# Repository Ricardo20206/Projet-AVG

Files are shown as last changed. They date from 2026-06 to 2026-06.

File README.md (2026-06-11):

# Projet-AVG

Carte électronique de **monitoring** basée sur un microcontrôleur **ESP32**, réalisée dans le cadre du projet **Équipe 4 — GROUPE WEED** (2026).

## Description

Ce dépôt contient la conception complète de la carte de monitoring AVG : schémas, routage PCB, bibliothèques de composants et documentation associée. Le projet est développé sous **Altium Designer**.

### Fonctionnalités principales

- Microcontrôleur **ESP32**
- Acquisition via **capteurs**
- Pilotage d'**actionneurs**
- Gestion d'un **circuit de priorité**
- Alimentation et **régulateurs**
- Interface **USB / UART**
- **Connecteurs** pour l'intégration système

## Structure du dépôt

| Dossier | Contenu |
|---|---|
| `10_doc_ext/` | Documentation externe (datasheets, recherches, …) |
| `20_doc_int/` | Documentation interne (suivi, notes de version, …)  |
| `30_src/` | Sources du projet Altium (schémas, PCB, bibliothèques) |
| `40_tmp/` | Fichiers temporaires (non versionnés) |
| `50_out/` | Fichiers générés (exports, sorties de fabrication) |
| `60_valid/` | Fichiers de validation et tests |

## Fichiers principaux (`30_src/`)

| Fichier / dossier | Description |
|---|---|
| `ESP32_Projet.PrjPcb` | Projet Altium principal |
| `Feuille_2_ESP32.SchDoc` | Schéma ESP32 |
| `Capteurs.SchDoc` | Schéma capteurs |
| `Actionneur.SchDoc` | Schéma actionneurs |
| `Circuit de priorité.SchDoc` | Schéma circuit de priorité |
| `Regulateurs.SchDoc` | Schéma alimentation / régulateurs |
| `Connecteurs.SchDoc` | Schéma connecteurs |
| `USB_UART.SchDoc` | Schéma interface USB / UART |
| `PCB/PCB11.PcbDoc` | Carte imprimée |
| `Rapport de la carte de monitoring AVG..pdf` | Rapport de conception |

## Prérequis

- [Altium Designer](https://www.altium.com/altium-designer) (version compatible avec les fichiers du projet)
- Accès aux bibliothèques `SCHLibrary.SchLib` et `PCBLibrary.PcbLib` incluses dans le dépôt

## Ouverture du projet

1. Cloner le dépôt :
   ```bash
   git clone https://github.com/Ricardo20206/Projet-AVG.git
   ```
2. Ouvrir Altium Designer.
3. Charger le fichier `30_src/ESP32_Projet.PrjPcb`.

## Équipe

**Équipe 4 — GROUPE WEED**

## Licence

À définir.

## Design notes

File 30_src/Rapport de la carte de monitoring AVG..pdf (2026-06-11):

MASTERE 1 ROBOTIQUE

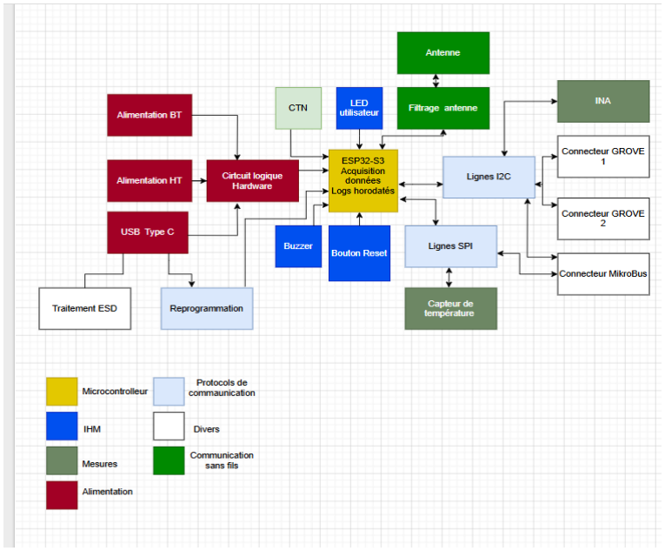
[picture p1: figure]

Rédiger par MBE SOB RICARDO

DOCUMENTATION TECHNIQUE – CARTE DE MONITORING4 AGV

Conception d'une carte embarquée pour AGV Ventec System Date: 07/05/2026
Groupe : WEED
Équipe :
MBE SOB Ricardo (CHEF DE PRPOJET) NGNINTEDEM TSOBENG Melkiade LE ROYER Edwin
MEYE ME NGUEMA Dan Irnel

ANALYSE FONCTIONNELLE (AF1 & AF2)

1- Architecture générale

Figure 1 : Architecture générale

2- Détail des blocs fonctionnels

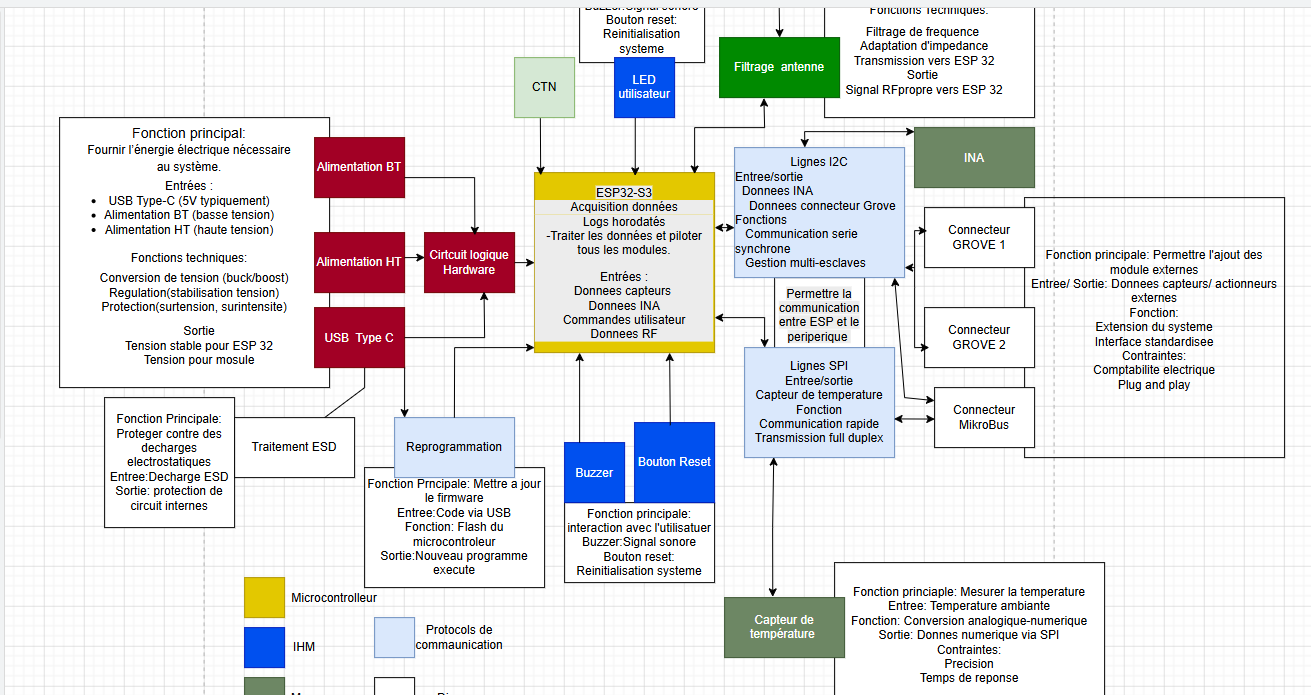
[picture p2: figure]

Figure 2 : Détail des blocs fonctionnels (AF2)

3- Alimentation

Les AGV de Ventec Systems sont équipés d'une batterie lithium 36V qui alimente en permanence l'ensemble des systèmes embarqués : motorisation, navigation, sécurité laser. Cette batterie ne peut pas être débranchée en cours d'exploitation, la couper reviendrait à couper l'alimentation des capteurs de sécurité et du système de navigation, ce qui est interdit par les procédures de sécurité en entrepôt. La carte de monitoring doit donc fonctionner en permanence sur cette source HT.
Lors d'une intervention de maintenance, le technicien doit avoir deux options pour se connecter à la carte sans couper le 36V :
- Brancher son PC portable via USB-C pour reprogrammer le firmware ou extraire les logs complets
- Connecter une batterie externe de service (3,7–10V) sur le connecteur BT pour alimenter la carte de façon isolée si le 36V doit être retiré pour une intervention lourde sur la batterie principale

La gestion de priorité (USB > BT > HT) garantit qu'une seule source est active à la fois et protège la carte dans tous les scénarios d'intervention. Pour éviter tout type d’accident, nous souhaitons un fonctionnement matériel, ce qui nous permet d’éviter les erreurs liées au firmware.

3.1- Conversion HT (36V) en 3V3
La conversion de cette tension est assurée par le régulateur de tension Buck LMR50410Y3FQDBVRQ1 qui convertit 36V_sh en 3.3V. Sur ce schéma l’entrée en tension vient de la sortie de la résistance shunt du capteur de courant et sa sortie en tension est nommée +3V3_HT.

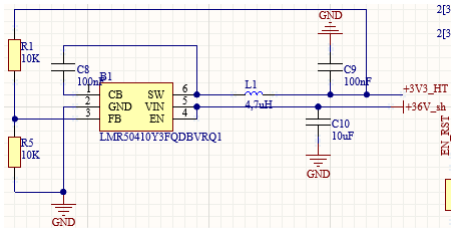
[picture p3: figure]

Figure 3 : Régulateur LMR50410Y3FQDBVRQ1

3.2- | conversion BT (3,7-10V) en 3V3
Cette | conversion est assurée par le | régulateur de tension | Buck
TPS62056DGSG4. Sur ce schéma l’entrée en tension est nommée +10V et la sortie +3V3_BT.

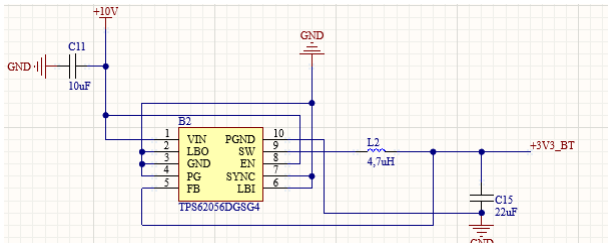
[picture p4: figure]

Figure 4 : Régulateur TPS62056DGSG4

3.3- Conversion USB-C en 3V3

La tension USB-C est fournie par le VBUS (5V) et est ensuite convertie en 3.3V par le régulateur linéaire LDO (Low Dropout regulator) NCP167BMX330TBG.

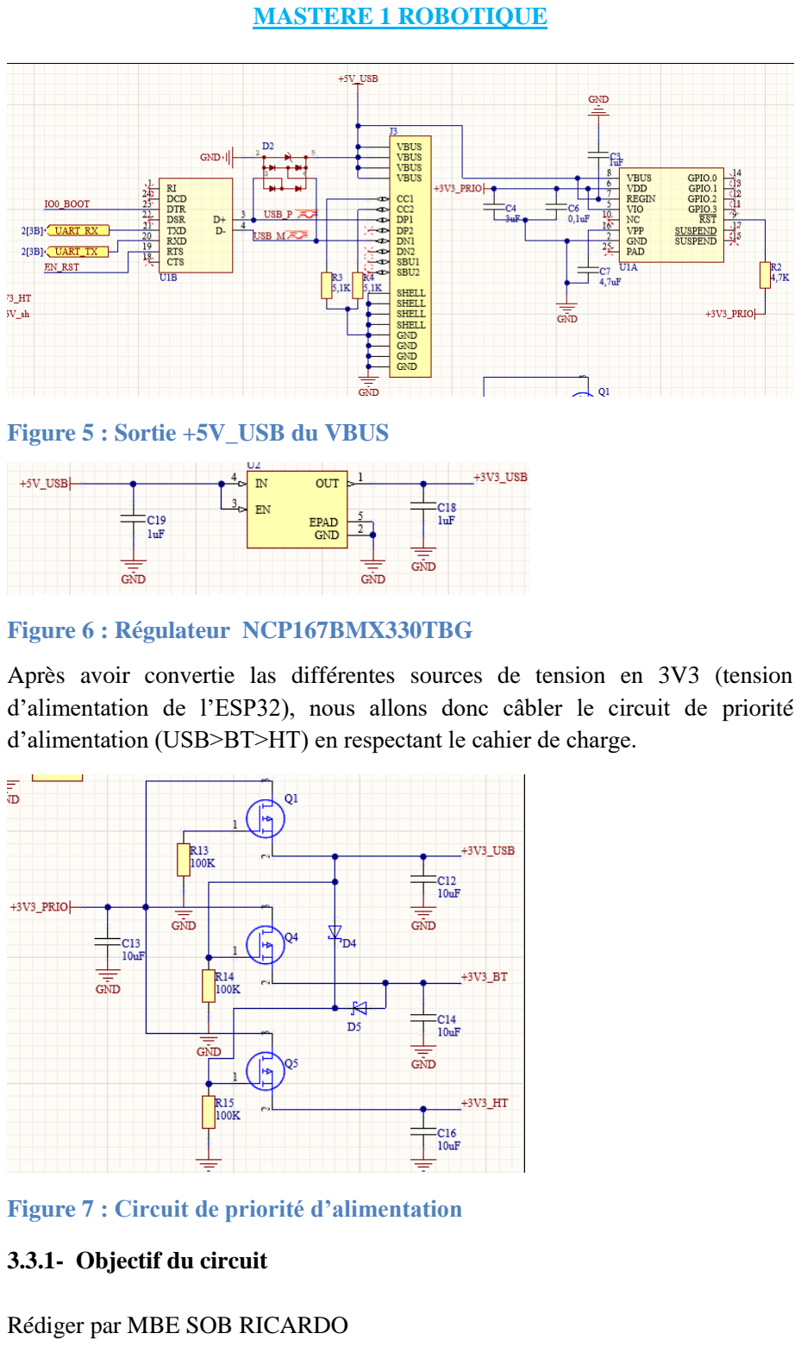
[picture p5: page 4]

Figure 5 : Sortie +5V_USB du VBUS

Figure 6 : Régulateur NCP167BMX330TBG

Après avoir convertie las différentes sources de tension en 3V3 (tension d’alimentation de l’ESP32), nous allons donc câbler le circuit de priorité d’alimentation (USB>BT>HT) en respectant le cahier de charge.

Figure 7 : Circuit de priorité d’alimentation

3.3.1- Objectif du circuit

Ce circuit assure l'alimentation continue d'une carte électronique à base d'ESP32-PICO-D4 en gérant automatiquement trois sources d'énergie selon un ordre de priorité strict :

USB (priorité 1) > Batterie/BT (priorité 2) > Haute Tension/HT (priorité 3)

La source HT est toujours présente et constitue l'alimentation de secours permanente.

3.3.2- Composants principaux

Composants | Référence | Rôle
Q1, Q4, Q5 | SI3139K-TP (P-MOS) | Interrupteurs de puissance
D4, D5 | SD103AWS-7-F (Schottky) | Protection anti-retour sur les sources USB et BT.
R13, R14, R15 | 100KΩ | Pull-down des gates vers GND
C12, C13, C14, C16 | 10µF | Découplage et filtrage

3.3.3- Principe de fonctionnement des MOSFET P-channel

Le SI3139K-TP est un transistor à effet de champ de type P. Sa logique de commutation est la suivante :

- Lorsque la tension de gate est significativement inférieure à la tension de source → le transistor conduit
- Lorsque la tension de gate est égale ou proche de la tension de source → le transistor est bloqué

Le seuil de conduction (Vgs(th)) est de −0.8V maximum, parfaitement compatible avec une alimentation 3.3V.

3.3.4- Rôle des résistances de gate (R13, R14, R15 = 100KΩ)

Chaque résistance relie la gate de son MOSFET au GND. En l'absence de toute tension de commande, elles tirent la gate vers 0V. Avec une source à +3.3V, cela crée un Vgs = −3.3V, maintenant les transistors en conduction par défaut. C'est le comportement de base sur lequel repose toute la logique de priorité.

3.3.5- Rôle des diodes Schottky SD103AWS-7-F

D4 et D5 sont placées exclusivement sur les lignes de gate de Q4 et Q5 :

- D4 laisse passer +3V3_USB vers la gate de Q4 pour le bloquer quand USB est présent, et empêche tout retour de courant vers le rail USB

- D5 laisse passer +3V3_USB et +3V3_BT vers la gate de Q5 via deux chemins distincts, et empêche tout retour de courant entre les rails USB et BT.

La technologie Schottky garantit une chute de tension minimale (~0.37V à faible courant) et une commutation ultra-rapide (tRR = 10ns).

3.3.6- Logique de priorité — Fonctionnement détaillé

Cas 1 — USB présent (priorité maximale)

Lorsque +3V3_USB est disponible :

- +3V3_USB est appliqué sur la gate de Q4 directement et sur la gate de Q5 via D4 et D5
- Pour Q4 : gate = +3V3_USB, source = +3V3_BT → Vgs ≈ 0V → Q4 bloqué
- Pour Q5 : gate = +3V3_USB, source = +3V3_HT → Vgs ≈ 0V → Q5 bloqué
- Gate de Q1 tirée vers GND par R13 directement → Vgs = −3.3V → Q1 conduit
- Résultat : seul Q1 conduit, l'ESP32 est alimenté par USB

Cas 2 — USB absent, BT présent (priorité 2)

Lorsque +3V3_USB disparaît :

- Gate de Q4 tirée vers GND par R14 → Vgs Q4 = −3.3V → Q4 conduit
- +3V3_BT est appliqué sur la gate de Q5 via D5 → Vgs Q5 ≈ 0V → Q5 bloqué
- D4 bloque tout retour de courant BT vers le rail USB
- Q1 sans source USB → bloqué naturellement
- Résultat : seul Q4 conduit, l'ESP32 est alimenté par BT

Cas 3 — USB et BT absents, HT seul (priorité 3)

Lorsque les deux sources principales sont absentes :

- Gates de Q4 et Q5 tirées vers GND par R14 et R15
- Q4 sans source BT → bloqué naturellement
- Gate Q5 = 0V, source = +3V3_HT → Vgs = −3.3V → Q5 conduit
- Q1 sans source USB → bloqué naturellement
- Résultat : seul Q5 conduit, l'ESP32 est alimenté par HT.

3.3.7- Condensateurs de découplage

Condensateur | Position | Rôle
C13 (10µF) | Entrée +3V3_PRIO | Filtrage de l'alimentation principale
C12 (10µF) | Sortie +3V3_USB | Absorption des transitoires USB
C14 (10µF) | Sortie +3V3_BT | Stabilisation BT
C16 (10µF) | Sortie +3V3_HT | Stabilisation HT

Table de vérité :

Cas | USB | BT | HT | Q1 | Q4 | Q5 | Source active | V_out
1 | 1 | 1 | 1 | ON | OFF | OFF | USB | 3.13V
2 | 1 | 1 | 0 | ON | OFF | OFF | USB | 3.13V
3 | 1 | 0 | 1 | ON | OFF | OFF | USB | 3.13V
4 | 1 | 0 | 0 | ON | OFF | OFF | USB | 3.13V
5 | 0 | 1 | 1 | OFF | ON | OFF | BT | 3.13V
6 | 0 | 1 | 0 | OFF | ON | OFF | BT | 3.13V
7 | 0 | 0 | 1 | OFF | OFF | ON | HT | 3.13V
8 | 0 | 0 | 0 | OFF | OFF | OFF | RIEN | 0V

4- Mesure de consommation électrique

4.1- Shunt de courant AEC-Q200

Un shunt de 1 mOhm (référence PSR400ITQFF0L50) est place en série sur la ligne 36V, entre la batterie et le reste du système (cote high-side). Ce composant est certifie AEC-Q200, norme obligatoire imposée par Ventec pour tous les composants passifs embarques sur ses AGV en raison des vibrations permanentes et des cycles thermiques.
Dimensionnement :
- Plage de mesure : 0 à 30A -> Vshunt_max = 30A x 1mOhm = 30 mV
- Puissance dissipée max : P = I2 x R = 302 x 0.001 = 0.9W (le boitier 2512 supporte jusqu'à 1W)
- Points de test : P1 IN+ et P2 IN- exposés en bord de carte pour mesure au voltmètre
- Résistances de simulation : deux résistances de précision (0.1%) permettent d'injecter une tension calibrée aux bornes de l'INA237 pour validation en laboratoire.
4.2- Amplificateur de mesure INA237AIDGST

L'INA237 de Texas Instruments est un amplificateur de mesure de courant/puissance bidirectionnel, high-side, communiquant en I2C (adresse 0x40). Il mesure simultanément la tension aux bornes du shunt et la tension du bus (36V via diviseur résistif interne).
Parametre Valeur
Tension bus max 36V (40V abs max)
Plage shunt +/- 81.92 mV (full-scale) Resolution shunt 2.5 uV / LSB
Precision +/- 0.1% (gain) + 10 uV (offset)
Interface I2C, adresse 0x40
Freq. échantillonnage Configurable : 140us a 8.244ms
Alimentation 2.7V a 5.5V (sur rail 3.3V)

Avec une résolution de 2.5 uV par LSB et un shunt de 1 mOhm, la résolution en courant est de 2.5 mA. La détection de dérives de 0.5A est donc assurée avec une très large marge. Le câblage du shunt doit respecter une connexion Kelvin (4 fils) pour éliminer la résistance des pistes PCB de la mesure.
5- Reprogrammation terrain
Cette reprogrammation se fait automatiquement en connectant le PC au port USB et en utilisant le firmware. Donc plus besoin d’utiliser les boutons BOOT et RESET.

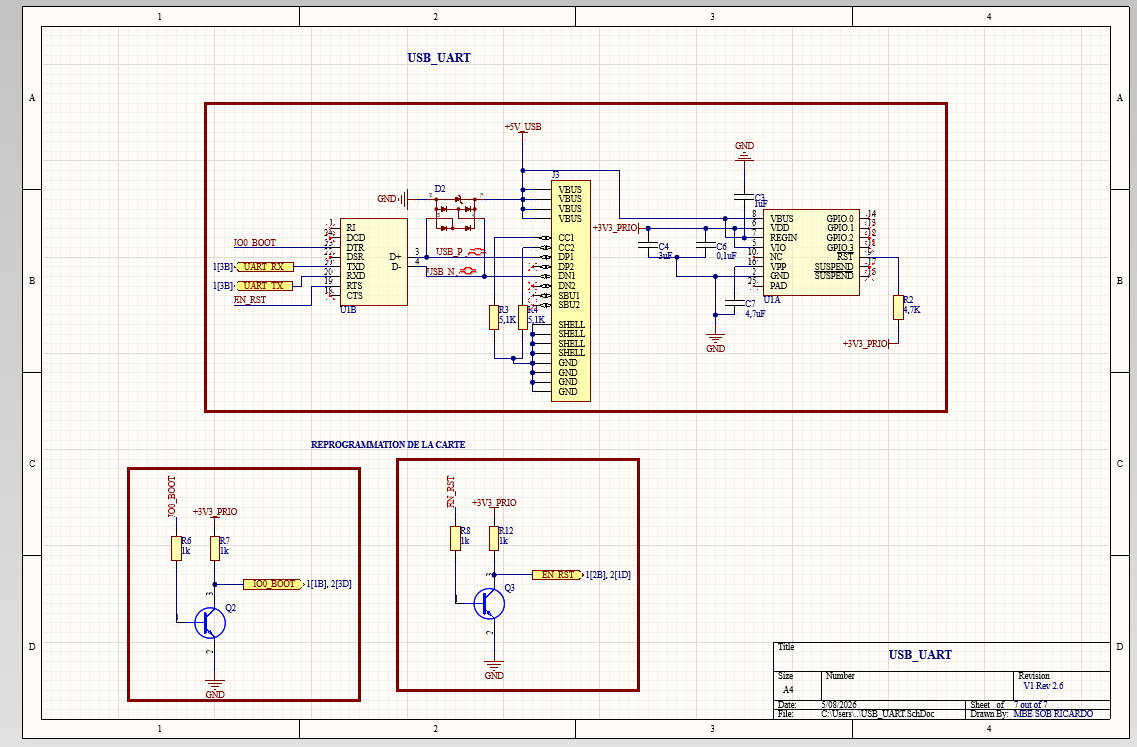
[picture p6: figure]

Figure 8 : circuit de reprogrammation

### 6. Extensibilité des capteurs

Exigences couvertes : EXF-28 a EXF-31
Connecteur Interface Capteur prevu Adresse I2C Usage
Grove 1 I2C (SDA/SCL) ADXL345 (accel.) 0x53 Detection vibrations/chocs Grove 2 I2C (SDA/SCL) SHT31 (humid.) 0x44 Surveillance frigorifique
MikroBus | SPI | (MOSI/MISO/SCK/CS)RFM95W | (LoRa) | N/A | (SPI)
Transmission longue portée

Les connecteurs Grove sont au format standard 4 pins (VCC 3.3V, GND, SDA, SCL) avec des résistances de pull-up de 4.7 kOhm déjà intégrées sur la carte pour le bus I2C. Le connecteur MikroBus suit le Standard MikroElektronika avec les signaux SPI, UART, I2C, PWM, GPIO, et les alimentations 3.3V/GND.

### 7. Tableau des adresses I2C

Exigence couverte : EXF-31 (OBLIGATOIRE)
Composant Adresse I2C Fonction Tension logique Conflit INA237 0x40- Mesure courant/puissance- 3.3V –Aucun conflit
SHT31 (Grove 2) 0x44- Humidité + température 3.3V- Aucun conflit TMP102 0x48- Température ambiante- 3.3V –Aucun conflit
ADXL345 (Grove 1) 0x53 -Accéléromètre / vibrations -3.3V –Aucun conflit

Toutes les adresses sont uniques sur le bus I2C. Les resistances de pull-up (4.7 kOhm) sont intégrées sur la carte principale. Les capteurs externes (Grove) ne doivent pas comporter leurs propres pull-ups pour éviter de surcharger le bus.

8- DIFFICULTÉS RENCONTRÉES ET SOLUTIONS
Problème 1 :
Constat
Lors de la validation du circuit de priorité d'alimentation, nous avons mesuré une tension de sortie de 3,13V alors que l'ESP32 nécessite 3,3V nominal. En charge maximale, cette tension descendait à 2,88V, passant sous le seuil minimal de 3,0V de l'ESP32.

Analyse
La cause principale est la présence des diodes Schottky (D4, D5) sur le chemin de puissance. Chaque diode génère une chute de tension de 0,37V. Cumulée aux chutes des MOSFETs (RDS = 0.7 ohm) et aux tolérances des convertisseurs, la tension finale devenait insuffisante.
Solution
Les diodes Schottky ont été supprimées du chemin de puissance. La commutation est désormais assurée uniquement par les MOSFETs. Une seule diode est conservée en protection anti-retour, mais placée après le MOSFET pour ne pas impacter la tension d'alimentation.
Résultat
La tension de sortie du circuit de priorité est maintenant de 3,13V, soit une marge de 0,13V au-dessus du seuil minimal de l'ESP32. Le fonctionnement est garanti sur toute la plage de courant.
Problème 2 :
Constat
Lors de l'intégration des capteurs sur le bus I2C, l'INA237 (mesure courant) et le capteur d'humidité HTU21D partageaient la même adresse 0x40, rendant leur communication simultanée impossible.
Analyse
L'INA237 possède une adresse configurable via ses broches A0 et A1. Le HTU21D a une adresse fixe non modifiable. Par défaut, l'INA237 est configuré en 0x40, ce qui crée un conflit direct avec le HTU21D.

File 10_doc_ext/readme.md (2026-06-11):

Documentations externes: recherches, datasheets, …

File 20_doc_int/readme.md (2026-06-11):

# Contenu de ce répertoire
Documents concernant uniquement ce dépot, release note, suivi, …

# Autres notes Adri
Ticket "Microcontrôleur: Affectation des pinout": clairitec/10_projects/int/selfenergy/slim-60-proj#8

# Taille de code
Suivi de la taille du code source

26/04/2023 v3.0.0 
```
DATA     0001426(00592H) Byte(s)
ROMDATA  0000976(003D0H) Byte(s)
CODE     0025787(064BBH) Byte(s)
```
27/04/2023 v3.0.1: adaptation IO hardware SLIM+60v3.0
```
DATA     0001416(00588H) Byte(s)	-10
ROMDATA  0000976(003D0H) Byte(s)
CODE     0025249(062A1H) Byte(s)	-538
```
27/04/2023 v3.0.1: #define DEBUG_SANS_BOOT_LOADER
```
DATA     0001416(00588H) Byte(s)
ROMDATA  0001012(003F4H) Byte(s)
CODE     0025249(062A1H) Byte(s)
```
02/05/2023 v3.0.2: Modif init LED + nom de defines
```
DATA     0001416(00588H) Byte(s)
ROMDATA  0001012(003F4H) Byte(s)
CODE     0025249(062A1H) Byte(s)
```
